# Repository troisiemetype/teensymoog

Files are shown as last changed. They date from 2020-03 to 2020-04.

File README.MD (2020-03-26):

# TeensyMoog

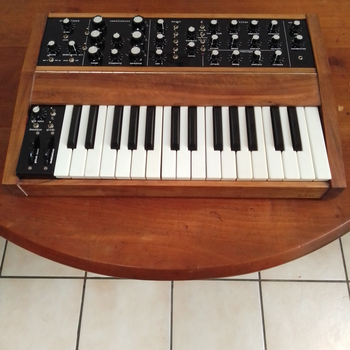
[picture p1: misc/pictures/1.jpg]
teensymoog 1

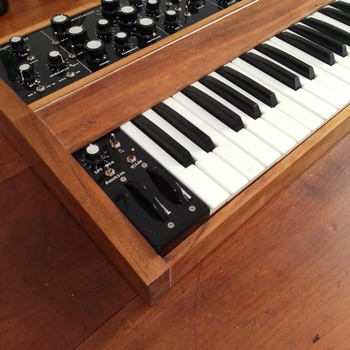
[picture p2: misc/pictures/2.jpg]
teensymoog 2

## What is it ?
_Teensymoog_ is a synth, inspired by the legendary minimoog.

It aims at looking and functioning as close as possible of the orinal, but using digital tools, namely Teensy and Arduino boards.

It uses three boards, one Teensy 4.0 that handles the heavy computing (sound generation), and two Arduino Mega (chinese copies in a small form factor), that are used as "port expander", which read keys, switches and potentiometers and send their value on change to the Teensy.

## How it's made :
It's based on a Teensy 4.0 running the incredible audio library by _Paul Stoffregen_ of [PJRC.com](https://www.pjrc.com/teensy/td_libs_Audio.html).

The whole interface (`minimoog_teensy/audio_setup.h`) has been developped with the associate [visual online audio system design tool](https://www.pjrc.com/teensy/gui)

Two Arduino Mega pro are used to poll all the switches and potentiometer and sending any update to the teesny. The communication between the boards uses MIDI messages, mainly control change (or continuous control) messages. I've tried to stick as close as possible to the MIDI specification, and using the existing and available control numbers. There are cases where it's not the case (_e.g._ filter cutoff frequency uses a two bytes control change to increase resolution).

A Pimoroni's phatDAC is used to output high quality audio from the i2s stream generated by the audio library. A USB B port is mounted on the rear panel so the synth can be connected to anything, as a USB midi device or USB audio device (not available in Arduino IDE for Teensy 4.0 yet, but I know it will come !). There is also provision for (not implemented yet !) MIDI in and out (DIN-5 pins, but maybe 3.5 jack would be a better idea) sustain and expression.

A smartphone charger has been repurpose as the main adaptor.

The enclosure has been made out of would and acrylic.

The base plate is made of plywood. The mains parts are made of walnut, from a table I found in the street two years ago. For a long time I wanted to repair it, but I didn't like its feet, so this is a good opportunity to make room in there ! The wood has been treated with tung oil, wich gives a soft and smooth finish that I really love.

The main and lateral control panels, control panel bottom and rear enclosure are made of 2mm acrylic (PMMA). It has been cut and engrave with a CO2 laser cutter. The engravures are filled with white paint. SVG files for the panels are included in the repository.

There was no sketch made for the walnut enclosure, but I should have done some : it's quite thin (around 7cm tall), and it gave me headaches to integrate some components in it. There is plenty of room, but I had to change things several time to accomodate the keyboard height, the front panel with sontrols and the rear panel with plugs...

#### Dependencies
Apart from Teensy audio, this program uses a few libraries.
[Arduino Midi library by FortySevenEffects](https://github.com/FortySevenEffects/arduino_midi_library), for internal communication between the boards. It's the one implemented by Teensy for usb MIDI, very complete.

[PushButton](https://github.com/troisiemetype/PushButton) is used to debounce all switches, and detect changes.

[expFilter](https://github.com/troisiemetype/expfilter) is used to smooth ADC readings. It gives a result close to a running average, but without the need of big tables to store results.

## Function implemented
As said above, the goal is to have something looking as close as possible to the original Minimoog.

The keyboard is smaller, 2 1/2 cotaves instead of 3 1/2 (or 30 keys instead of 44), not by choice, but because the _Bontempi_ electric organ it cames from.

### Global description
It has three oscillators, a mixer section with noise and feedback (post-filter output is re-fed to the mixer), a filter, two envelopes generator for filter and notes, a LFO, a pitchbend wheel and a modulation wheel.

### Oscillators
Oscillators have each six waveforms to choose from, six frequency range (or octave transposition) and osc. 2 & 3 can be detuned by +- 1 octave regarding the base note. Osc.3 can be disconnected from the keyboard control, and used as a drone.

### Noise
There is one noise source, with pink and white noise.

### Feedback
The original minimoog has a external input mixer entry, so anything (guitar, another synth, etc) could be processed through the mixer. It was often used as a feedback path by plugin the headphone jack back into this input. The minimoog reissue has hard-wired this by connecting the output to this external input internally when nothing is connected to the jack.

Maybe external input will be implemented once, but I wanted this feedback.

### Mixer
The mixer is copy-paste on the original minimoog : a potentiometer for each of the five channels, and a switch for rapid on / off.

### Filter
The filter is (I believe) close from the minimoog one. Cutoff frequency and emphasis (resonance) are available. Their is an associated envelope generator that modulates the cutoff frequency. Their is also an addition compared to the minimoog : there is a knob to slide continuously from low pass to band pass, to high pass filter. It can also slide continuously from low pass to high pass, thus resulting in a band stop filter at mid-course. (see _functions_ above)

### Envelope generator
There are two envelope generators : one for the filter, the other for the global sound shape. On the original minimoog, decay can be used (_via_ a switch) to add release to notes. On this one a knob is there for, so this is a classic ADSR envelope.

### LFO
There is a LFO available, with continuous rate and waveform selection.

### Modulation
The modulation can be applied to oscillators and or filter, and is controlled by the modulation wheel. Four modulation sources can be used, and mix together. osc.3 or filter envelope can be mixed to noise or LFO.

### Glide (portamento)
Portamento can be from 0 to ten seconds, and switch on and off.

### Octave transpose
There is +- 2 octave transpose available to compensate the only 2 1/2 octave from the keyboard.

### Function settings
There are "hidden" settings available through a function switch. When turn on, the keyboard can be used to change the behavior of some things. Each of this setting is saved when power is turned off.
The first octave of the keyboard is used to select the setting to be changed, then keys from the second C used to set the new value.

#### Keyboard priority mode
_Function + C_

This defines the way the keyboard behave. There are four mode available :
1. lower note priority : a note will be played only if it's lower than the one already playing.
1. first note priority : a note will be played only if no note is already playing.
1. last note priority : a note will be played anyway.
1. upper note priority : a note will be played only if it's upper than the one already playing.
In any case, ten notes are tracked, so when several key are pressed releasing a key will play another, according to their position or the order they was pressed.

#### Note retrigger
_Function + D_

This defines how a new note is played. If some keys are already pressed when a new note is played, it can retrigger the envelopes, or let them to their state. This can be turned on or off.

#### Keyboard detune
_Function + E_

The original minimoog has a resistor ladder keyboard, which implies small variations in tonality regarding a perfect pitch. This setting reproduce this by applying detune to each note and letting you choice : 
1. off : perfect pitch for each key
1. soft : lightly detuned, +-10% of a semitone
1. medium : a bit more detuned, +-30%
1. hard : play drunk, two adjacent notes can almost same the same, +-50%
1. reset : this generate a new random detune table.
The detune table stores a fix detune coefficient for each of all 128 MIDI notes.

#### Bitcrush
_Function + F_

Output resolution can be changed. The default is 16 bits, but any bitsize between 4 and 16 can be choose.
The bitcrushing is applied at the end of the audio stream, just before the i2s / USB output.

#### Filter mode
_Function + G_

The filter band knob slides continuously from low pass to high pass. It can be choosen wether :
* it slides from low pass to band pass for the lower half (high pass cut), and from band pass to high pass in the upper half (low pass cut), or
* it slides continuously from low pass to high pass, thus resulting in a band stop filter when knob is centered. (well, kind of : having a true band stop filter would mean to mix two different filters with frequency offsets. Here they overlap.)

#### MIDI channel setting
_Function + A_ for MIDI in

_Function + B_ for MIDI out

The MIDI channel the synth listens and emit on when connected _via_ USB can be changed. Any channel from 1 to 16.

#### Pitchbend range
_Function + pitchbend wheel move_

The amount the pitch wheel bends a note above or bellow the note being played can be changed semitone by semitone.

#### Modulation range
_Function + modulation wheel move_

As well as the pitch bend range can be changed, so does the modulation range. Pressing any key will set this interval according to second C, for the modulation applied to oscillators. Modulation applied to filter can be changed as well, by pressing second C before to set the new interval.

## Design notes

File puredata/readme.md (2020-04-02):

### Pure Data patches
These patch has been used when writing the main code running on Teensy, to setup the audio layout and test things.
The panel sends the CC on midi channel 1.
The (very basic !) keyboard sends note on and note off on channel 1 too.

You can use it by uncommenting the 4 usbMIDI commented lines in setup, that maps the  usbMIDI to internal midi functions. The majority of the audio functions of the synth can be accessed, without having a physical interface, like keyboard, knobs, switches, etc. The only thing you need here is the Teensy and an audio DAC.

It has been used before the CC LSB were implemented, so maybe

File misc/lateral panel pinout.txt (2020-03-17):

0		GND
1		5V
2		pitch bend
3		mod wheel
4		LFO rate
5		glide
6		LFO shape
7		function
8		not used

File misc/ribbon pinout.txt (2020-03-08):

0		5V
1		GND
2		modulation mix
3		glide
4		osc1 range
5		osc2 range
6		osc3 range
7		osc1 waveform
8		osc2 waveform
9		osc3 waveform
10		osc1 mix
11		osc2 mix
12		osc3 mix
13		noise mix
14		feedback mix
15		modulation mix 1
16		modulation mix 2
17		osc modulation
18		osc3 ctrl
19		transpose +
20		transpose -
21		osc1 mix sw
22		osc2 mix sw
23		osc3 mix sw
24		noise mix sw
25		feedback mix sw
26		noise color
27		mega 2 rx from teensy
28		mega 2 tx to teensy
29		mega 2 reset
30		
31		
32		
33

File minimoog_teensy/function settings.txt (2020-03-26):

Keyboard mode
				note : in any case, when there are several notes pressed, releasing one will trigger another, according to priority mode.
	first		The first key pressed has priority. It must be released for another to trigger note
	last		Last key pressed triggers new note.
	lower		The lower key on the keyboard has priority
	upper		The upper key has priority

Bitcrush
				bit crusher : reduce resolution of the samples before output
	4 - 16

Midi in channel
				the channel the synth reacts to when connected to USB MIDI
	1 - 16

Midi out channel
				the channel the synths sends on
	1 - 16

Retrigger
				when a key is pressed and there was already one (or several), retrigger the envelope or no
	0 / 1

Detune
				Add a small amount of detune to each note, to simulate a resistor ladder vintage keyboard
	off
	soft
	medium
	hard
	reset

filter mode
				The filter band can be changed steplessly from low pass to high pass.
				This gives the choice of how it behave at mid course
	Band pass	The lower half of the control mixes low pass with band pass. High pass cut.
				The upper half mixes band pass with high pass. Low pass cut.
	Band stop	The low and high pass are mixed continuously, band pass cut, resulting in a band stop
				on middle position.

pitchbend range
				Any interval regarding the note beeing played can be choosen for the pitchbend.

modulation range
				The modulation range can be changed independently for the oscillators and for the filter.

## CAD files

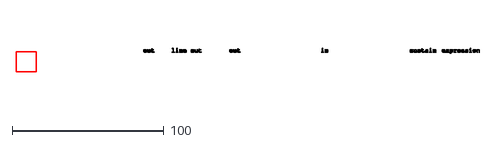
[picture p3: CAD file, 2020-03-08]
panels/dxf/minimoog - capot arrière inferieur - texte.dxf
306.0 x 15.5

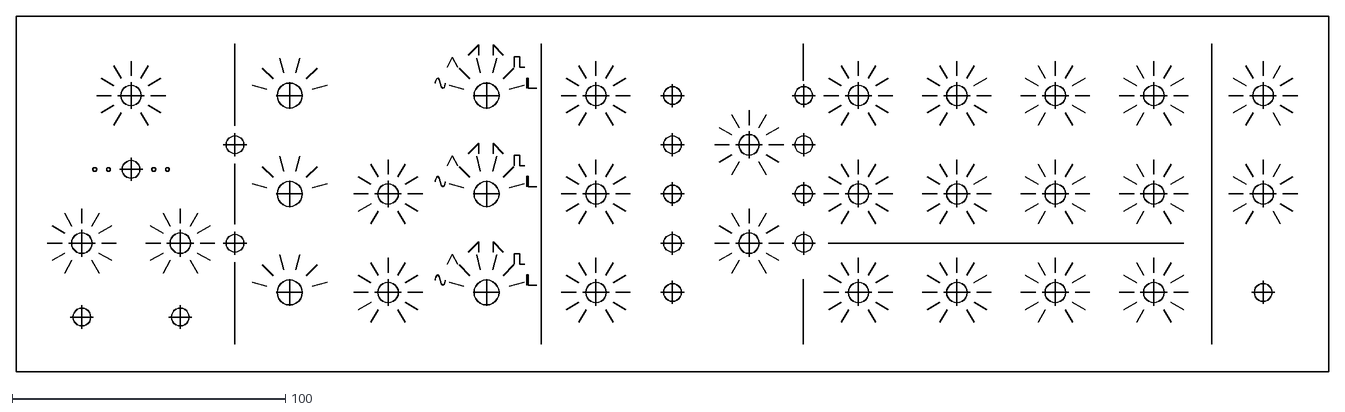
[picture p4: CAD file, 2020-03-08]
panels/dxf/minimoog - facade.dxf
480.0 x 130.0

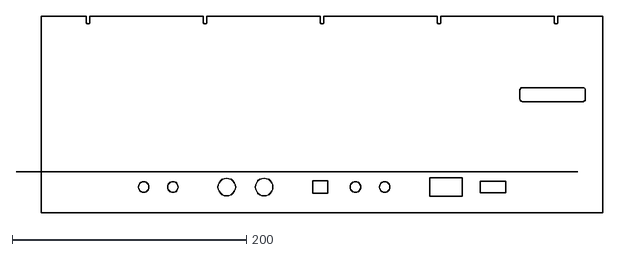
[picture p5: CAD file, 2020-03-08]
panels/dxf/minimoog - capot arrière inferieur.dxf
501.5 x 168.0

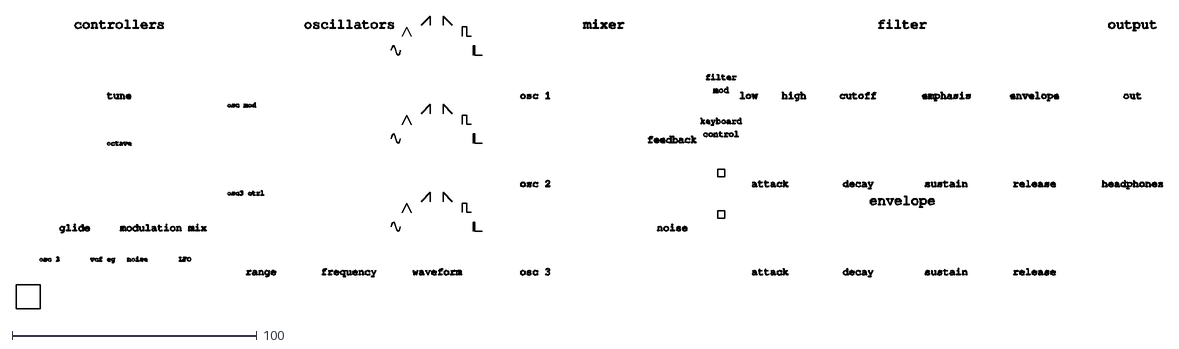
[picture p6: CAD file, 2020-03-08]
panels/dxf/minimoog - facade 3 - texte applati.dxf
468.4 x 119.5

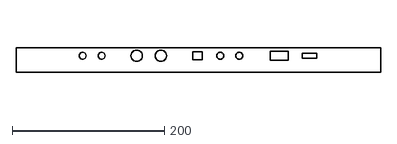
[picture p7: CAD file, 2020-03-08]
panels/dxf/minimoog - capot arrière inferieur - doublure.dxf
479.7 x 32.7

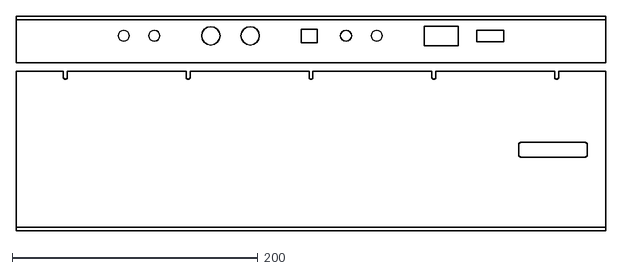
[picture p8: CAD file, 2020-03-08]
panels/dxf/minimoog - capot fond inferieur.dxf
480.0 x 174.7

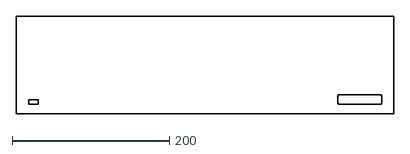
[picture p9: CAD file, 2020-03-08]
panels/dxf/minimoog - capot arrière supérieur.dxf
480.0 x 123.8

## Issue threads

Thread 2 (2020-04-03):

Good job!

benwadub, 2020-04-03:
Hello, i just start my investigation to make my first teensy synth and I called on your project it seems very good!
Is it possible to use only the teensy .ino to play the synth with a teensy controller already built or an existing midi keyboard?
I m looking for a project to start with cause I m really new to programming so I need to learn and didn’t find how to use the audio library with my midi keyboard :-(
Sorry for my poor English I m French!

troisiemetype, 2020-04-03:
Hi Ben.

Pas de problème pour l'anglais, je ne relève pas, je suis français aussi ! ;)
(but I'll go on in english, sorry...)

You can use only the Teensy part, yes. You'll have some minor modifications to do, as :
* implement the MIDI-in part if you want to use MIDI DIN connectors. It should be straightforward, you just have to create a hardware Serial (there are 7 on the Teensy 4.0, choose whichever you need). If you want to make the synth without the keyboard part, you just have to map note on and note off, pitchbend, and mod wheel. For modwheel you may need to create a handler new handler for CC and implement only modwheel in it, so the external midi don't mess with other CC that are used internally. If you want to control others things, you should as well implement them. Some controls I used have a different CC number, but 7 bits was not enough to me for some controls.
* Remember MIDI plugs have to be isolated with an optocoupler. You find schematics on the web. And maybe modules too.
* Teensy has not enough IO for every switches and potentiometers, that's why I used two others Mega boards. But the Audio part uses around 5% of the CPU time, so you can use a port expander or multiplexer to connect everything and handle it with Teensy. There's plenty of room for it.

Hope that answers to your questions !

benwadub, 2020-04-04:
No problem to continue in English, It s better for everyone that ´ll read this later! I ll check the teensy code, no problem for me to make a midi in/out/thru I already built one for my controler!
I ll try to make an expander version of your synth to sequence it with my elektron digitakt!
Merci du Jura

benwadub, 2020-04-04:
hi just a question, if my midi notes come from a sequencer via midi din does the teensy recognize all note on and note off? If not I don t know how to setup each midi note if they don t come from a pin or mux

troisiemetype, 2020-04-04:
Hi,

If you look at the code, you will see that are too handlers for note on and note off.
* One is the __internal__ handler. It takes every notes coming for the first Arduino mega, offset them (the mega sends pitch from 0 to 30), echo them to MIDI out, then sends them to :
* __global__ handler, which is also the __external__ handler. This one handles note priority priority mode, and calls _note on_ and _note off_ functions when needed.

It's the same for note off messages.

On the two tracks I've recorded with the synth, I've recorded the midi parts with Ardour, then quantize them and played back trough the synth to record audio. ;)

benwadub, 2020-04-04:
ok so if I understand well it should work out of the box!
I just have to compile your code and mine and I could control your synth with my controller!
does my code interest you? it s a midi mixer with 8 midi channels 40 pots 8 faders and 8 encoders, 8 midi notes and 8 buttons for mute using the great tttapa control surface library
I can give it to you if you want!

troisiemetype, 2020-04-04:
Yeah, it could be usefull ! I was thinking about making a midi mixer for easier use of Ardour ! Don't you have a repository for it ?

benwadub, 2020-04-04:
i don t have a repository, I m a very noob at all this! I m a food truck owner so with this corona crisis I get time to learn things here is my code
```cpp

#include <Encoder.h>

// celà doit etre écrit avant la library control surface
#include <Control_Surface.h> // Inclu la library control surface téléchargeable ici https://github.com/tttapa/Control-Surface en cliquant le bouton vert a droite
 //USBDebugMIDI_Interface midi = 115200; // enlever les // en début de ligne pour entrer en mode debug usb et voir dans le panneau de control si vos controler envoient bien les infos

//auto &serial = Serial1;// Selectionne le port série à utiliser remplacer par serial pour une arduino
USBMIDI_Interface usbmidi;// enlever les / en debut de ligne pour activer l'interface usb, penser à désactiver l'interface série(din)
//SerialMIDI_Interface<decltype(serial)> midi = {serial, MIDI_BAUD

//};// démarre une interface midi serial au midi baud rate par defaut

//  ces lignes midi servent à activer un bouton qui envoit une note midi enlever les // sur ces 5 lignes pour l'activer

// démarrer une touche midi

CD74HC4067 mux1 = {
  A2,       // numéro de broche de l'arduino
  {2, 3, 4, 5} // numéro de pins de l'arduino sur lesquels sont branchés tous les multiplexeurs apellés mux S0, S1, S2
};
Bank<2> bank2 = {8}; // active 2 bank avec 8 adresses par bank
//démarre un multiplexeur pour 8 boutons mute
Bankable::CCButtonLatched <8> buttonmute[] = { //ces lignes déclarent le mux
  {{bank2,BankType::CHANGE_CHANNEL}, mux1.pin(0), {94, CHANNEL_1}},//numéro de bank correspondant/indique que le changement de bank change le canal midi (+8 car on a 8 adresses par bank)/pin sur laquelle le controleur est branché/numéro de cc/numéro de canal midi
  {{bank2,BankType::CHANGE_CHANNEL},mux1.pin(1), {94, CHANNEL_2}},
  {{bank2,BankType::CHANGE_CHANNEL},mux1.pin(2), {94, CHANNEL_3}},
  {{bank2,BankType::CHANGE_CHANNEL},mux1.pin(3), {94, CHANNEL_4}},
  {{bank2,BankType::CHANGE_CHANNEL},mux1.pin(4), {94, CHANNEL_5}},
  {{bank2,BankType::CHANGE_CHANNEL},mux1.pin(5), {94, CHANNEL_6}},
  {{bank2,BankType::CHANGE_CHANNEL},mux1.pin(6), {94, CHANNEL_7}},
  {{bank2,BankType::CHANGE_CHANNEL},mux1.pin(7), {94, CHANNEL_8}},
};

Bank<2> bank1 = {-8}; // 2 banks, 8 addresse per banks

CD74HC4067 mux2 = {// deuxième multiplexeur cette fois si avec 16 entrées
  A0,              // analog pin
  {2, 3, 4, 5}, // numero de pin du mux S0, S1, S2, S3
  // 7, // Optionally, specify the enable pin
};
//Instantiate multiplexer for 16 switch
Bankable::CCPotentiometer fx [] = {
  {{bank1, BankType::CHANGE_ADDRESS},mux2.pin(0), {83, CHANNEL_1}},
  {{bank1, BankType::CHANGE_ADDRESS},mux2.pin(1), {83, CHANNEL_2}},
  {{bank1, BankType::CHANGE_ADDRESS},mux2.pin(2), {83, CHANNEL_3}},
  {{bank1, BankType::CHANGE_ADDRESS},mux2.pin(3), {83, CHANNEL_4}},
  {{bank1, BankType::CHANGE_ADDRESS},mux2.pin(4), {83, CHANNEL_5}},
  {{bank1, BankType::CHANGE_ADDRESS},mux2.pin(5), {83, CHANNEL_6}},
  {{bank1, BankType::CHANGE_ADDRESS},mux2.pin(6), {83, CHANNEL_7}},
  {{bank1, BankType::CHANGE_ADDRESS},mux2.pin(7), {83, CHANNEL_8}},
  {{bank1, BankType::CHANGE_ADDRESS},mux2.pin(8), {82, CHANNEL_1}},
  {{bank1, BankType::CHANGE_ADDRESS},mux2.pin(9), {82, CHANNEL_2}},
  {{bank1, BankType::CHANGE_ADDRESS},mux2.pin(10), {82, CHANNEL_3}},
  {{bank1, BankType::CHANGE_ADDRESS},mux2.pin(11), {82, CHANNEL_4}},
  {{bank1, BankType::CHANGE_ADDRESS},mux2.pin(12), {82, CHANNEL_5}},
  {{bank1, BankType::CHANGE_ADDRESS},mux2.pin(13), {82, CHANNEL_6}},
  {{bank1, BankType::CHANGE_ADDRESS},mux2.pin(14), {82, CHANNEL_7}},
  {{bank1, BankType::CHANGE_ADDRESS},mux2.pin(15), {82, CHANNEL_8}},
};

Bank <2> bank3 = {8}; // 2 banks, 8 addresse per banks

  //Instantiate second multiplexer for 8 potentiometer
CD74HC4067 mux3 = {
  A1
  ,       // Analog input pin
  {2, 3, 4, 5} // Address pins S0, S1, S2};

};
Bankable::CCPotentiometer fader [] = { //ici on déclare les faders avec comme vu plus haut le numéro de CC et le canal
  {{bank3, BankType::CHANGE_CHANNEL}, mux3.pin(0), {7, CHANNEL_1}},
  {{bank3, BankType::CHANGE_CHANNEL}, mux3.pin(1), {7, CHANNEL_2}},
  {{bank3, BankType::CHANGE_CHANNEL}, mux3.pin(2), {7, CHANNEL_3}},
  {{bank3, BankType::CHANGE_CHANNEL}, mux3.pin(3), {7, CHANNEL_4}},
  {{bank3, BankType::CHANGE_CHANNEL}, mux3.pin(4), {7, CHANNEL_5}},
  {{bank3, BankType::CHANGE_CHANNEL}, mux3.pin(5), {7, CHANNEL_6}},
  {{bank3, BankType::CHANGE_CHANNEL}, mux3.pin(6), {7, CHANNEL_7}},
  {{bank3, BankType::CHANGE_CHANNEL}, mux3.pin(7), {7, CHANNEL_8}},

};

CCAbsoluteEncoder encoder [16] = {
  {{6, 7}, {85, CHANNEL_16},8, 4,},// pins sur lesquels sont branchés les encodeurs/numero cc/canal midi/multiplicateur de vitesse/ nombre de cran par tic de l'encodeur
  {{8, 9}, {86, CHANNEL_16}, 16, 4,},
  {{10, 11}, {87, CHANNEL_16}, 16, 4,},
  {{12, 13}, {88, CHANNEL_16}, 16, 4,},
  {{17, 18}, {89, CHANNEL_16}, 16, 4,},
  {{19, 20}, {90, CHANNEL_16}, 16, 4,},
  {{21, 22}, {91, CHANNEL_16}, 16, 4,},
  {{24, 25}, {92, CHANNEL_16}, 16, 4,},
  /*
  {{26, 27}, {24, CHANNEL_16}, 16, 4,},
  {{28, 29}, {25, CHANNEL_16}, 16, 4,},
  {{30, 31}, {26, CHANNEL_16}, 16, 4,},
  {{32, 33}, {27, CHANNEL_16}, 16, 4,},
  {{34, 35}, {28, CHANNEL_16}, 16, 4,},
  {{36, 37}, {29, CHANNEL_16}, 16, 4,},
  {{38, 39}, {30, CHANNEL_16}, 16, 4,},
  {{A21, A22}, {31, CHANNEL_16}, 16, 4,},
*/
};

using namespace MIDI_Notes;

NoteButton pads[] = {
  {5, {note(C, 2), CHANNEL_1}},
  {6, {note(C, 2), CHANNEL_2}},
  {7, {note(C, 2), CHANNEL_3}},
  {8, {note(C, 2), CHANNEL_4}},
  {9, {note(C, 2), CHANNEL_5}},
  {10, {note(C, 2), CHANNEL_6}},
  {11, {note(C, 2), CHANNEL_7}},
  {12, {note(C, 2), CHANNEL_8}},// Note C4 on MIDI channel 1
};
void setup() {
  Control_Surface.begin(); // initialise la library surface de control

}                   
void loop() {

  Control_Surface.loop(); // Update the Control Surface

}```
feel free to use it mod it and share it
there is usb midi or serial you ll find easily how to switch!

benwadub, 2020-04-04:
I can t find how to send midi from usb with the teensy code and receive audio from usb too,
I changed the audio input in audio setup of the code
Ableton Live recognize the teensy as audio device
I included midiusb.h
but can't hear anything from the synth, could you explain all the midi interface in the sketch please?
I thought that the way I did I should send midi to teensy via usb and take the audio from teensy via usb
if you have can show me where I must investigate it would be nice!
(i don t have the teensy audio board for the moment it s why I d like to test via usb only for the moment!)

troisiemetype, 2020-04-04:
For MIDI in, you have nothing to do, it already works as is. At least for note triggering.
Every step in the audio chain is initialized, so you should hear something.
As you don't have external controls for now, you should comment out the two internal midi (that receive from Mega 1 and Mega 2) handler in setup.

You have to modify the audio_setup to replace I2S out by USB out. **And** you have to set the _USB type_ to MIDI + audio in the IDE before uploading your program to the board.

If you haven't seen it, there are explanations about how the audio library works, as well as a video tutorial that is worth the time.

Note : the stable version of Teensy loader doesn't include the option for USB audio on Teensy 4.0 yet, as it's under testing. But there is a beta version available (go and check the forum) which has it working.

benwadub, 2020-04-05:
i m on teensy3.5, I replaced audio output by usb and thought about the ice configuration too
i ll recheck the audio tutorial!

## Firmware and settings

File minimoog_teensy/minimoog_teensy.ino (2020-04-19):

// Minimoog - Teensy
/*
 * This program is part of a minimoog-like synthesizer based on teensy 4.0
 * Copyright (C) 2020  Pierre-Loup Martin
 *
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
 * You should have received a copy of the GNU General Public License
 * along with this program.  If not, see <http://www.gnu.org/licenses/>.
 */

/* This program is a synthesizer very similar to the minimoog model D.
 * It is intended to run on a Teensy 4.0, using the PJRC audio library.
 * It also uses two Arduino Mega boards to manage all the user inputs :
 * keyboard, switches, potentiometers, etc.
 * All user inputs are handled and send to the teensy board using midi commands
 */

 /*
  * Pinout
  *
  * RX from mega 1 (through tension divider) 		0
  * TX to mega 1 (serial 1)							1
  * mega 1 reset 									2
  * 	
  * RX from mega 2 (through tension divider) 		16
  * TX to mega 2 (serial 4)							17
  * mega 2 reset 									18
  * 	
  * I2S OUT1A 										7
  * I2S LRCLK1										20
  * I2S BCLK1 										21
  *
  * There are provision on the rear panel for sustain and expression control, not implemented yet.
  */

#include <Audio.h>
#include <Wire.h>
#include <SPI.h>
#include <SD.h>
#include <SerialFlash.h>
#include <EEPROM.h>

#include "audio_setup.h"
#include "defs.h"

#include "MIDI.h"					// https://github.com/troisiemetype/PushButton
// #include "Timer.h"

// constants

const int8_t MEMORY_ID = 0;

// my pots never go full clockwise... :/ So this can be used to adapt their range.
// These two commented out values for testing with external midi triggering (like puredata).
//const uint16_t RESO = 127;
//const uint16_t RESO = 16383;
const uint16_t RESO = 1005;
const uint16_t HALF_RESO = RESO / 2;

// There is a function that handles and tracks the key presses. Here is the max.
// It can me more, but whith ten fingers on a monophonic synth, I think this is enough !
const uint8_t KEYTRACK_MAX = 10;

// Mega1 sends midi note 0 for the lower note ; we offset it by for octave to get into the usefull range
const uint8_t MIDI_OFFSET = 48;
// To be modified according to keybed used. It's actualy not used, and any note can be handled from MIDI in.
const uint8_t NUM_KEYS = 30;

// Octave range for oscillators and filter.
const uint8_t MAX_OCTAVE = 10;
const uint8_t FILTER_MAX_OCTAVE = 5;

// The base for computing DC levels for keys, modulation, pitchbend, etc.
const float NOTE_MIDI_0 = 8.1757989156434;
const float NOTE_RATIO = 1.0594630943593;
const float HALFTONE_TO_DC = (float)1 / (MAX_OCTAVE * 12);
const float FILTER_HALFTONE_TO_DC = (float)1 / (FILTER_MAX_OCTAVE * 12);

// Filter base frequency : the filter cutoff frequency varies around this value.
const float FILTER_BASE_FREQUENCY = 440.0;
const float FILTER_BASE_NOTE = (log(FILTER_BASE_FREQUENCY / NOTE_MIDI_0)) / (log(NOTE_RATIO));
// This corresponds to the min and max values for the variable filter available in the Teensy Audio library,
// which is used by the synth.
/* Note about the state variable (Chamberlin) filter:
 * 	This filter can self oscillate, if given a resonnance value of around 50000.
 *	(and the library modified to accept such value ; the setter limits it to 5).
 *	It gives a nice sounding, pure sinewave.
 * 	Problem is, usefull range for varying resonnace is about what the bare library allows (from 0.7 to 5).
 *	It would be nice to test some exponential course to enable both continuous resonance modification AND self-oscillation.
 *	I've tried some modifications, but couldn't come to something usable.
 */
const float FILTER_MIN_Q = 0.7;
const float FILTER_MAX_Q = 5;
const float FILTER_DIV_Q = RESO / (FILTER_MAX_Q - FILTER_MIN_Q);

// Max mixer value for eahc channel if we want to avoid clipping.
// Value of 1 can be used, but induces distortion when more than one oscillator is used.
// Feedback should have its own value. If MAX_MIX is one feedback is powerfull,
// but with this value the difference with and without feedback is barrely noticeable.
const float MAX_MIX = 0.32;

// To be put in Mega1 sketch, so it sends a value on 14 bits.
// Note : the pitchbend wheel poses problems on the other sketch. For now it will stay like that,
// but there is room for improvement.
//343 - 492 - 500 - 651
const int16_t PITCH_BEND_MIN = 343;
const int16_t PITCH_BEND_MAX = 651;
const int16_t PITCH_BEND_NEUTRAL = PITCH_BEND_MIN + (PITCH_BEND_MAX - PITCH_BEND_MIN) / 2;
const int16_t PITCH_BEND_COURSE = PITCH_BEND_MAX - PITCH_BEND_MIN;
const float PITCH_BEND_INTERNAL_TO_MIDI = 8192.0 / PITCH_BEND_COURSE;

// Maximum attack, decay, release and glide time (in milliseconds)
// These use an exponential course to have both fine-tune of low values and a great range.
const float MAX_ATTACK_TIME = 10000;
const float MAX_DECAY_TIME = 10000;
const float MAX_RELEASE_TIME = 10000;
const float MAX_GLIDE_TIME = 10000;
/*
// Moved to Mega 1
const uint16_t MOD_WHEEL_MIN = 360;
const uint16_t MOD_WHEEL_MAX = 666;
const uint16_t MOD_WHEEL_NEUTRAL = MOD_WHEEL_MIN + (MOD_WHEEL_MAX - MOD_WHEEL_MIN) / 2;
const uint16_t MOD_WHEEL_COURSE = MOD_WHEEL_MAX - MOD_WHEEL_MIN;
*/

// Teensy can reset both Mega, if needed.
const uint8_t MEGA1_RST = 2;
const uint8_t MEGA2_RST = 18;

// Addresses for settings storing in memory. It uses Arduino's EEPROM functions but is saved to RAM on Teensy 4.0.
const uint16_t EE_MEMORY_INIT = 0;
const uint16_t EE_BITCRUSH_ADD = 3;
const uint16_t EE_KEYBOARD_MODE_ADD = 4;
const uint16_t EE_MIDI_IN_CH_ADD = 5;
const uint16_t EE_MIDI_OUT_CH_ADD = 6;
const uint16_t EE_TRIGGER_ADD = 7;
const uint16_t EE_DETUNE_ADD = 8;
const uint16_t EE_FILTER_MODE = 9;
const uint16_t EE_PITCH_BEND_RANGE = 10;
const uint16_t EE_MOD_WHEEL_OSC_RANGE = 11;
const uint16_t EE_MOD_WHEEL_FILTER_RANGE = 12;
const uint16_t EE_DETUNE_TABLE_ADD = 20;

// variables
// Note : 
uint8_t internalMidiChannel = 1;
uint8_t midiInChannel = 1;
uint8_t midiOutChannel = 1;

float glide = 0;
bool glideEn  = 0;

bool noteRetrigger = 1;

bool filterKeyTrack1 = 0;
bool filterKeyTrack2 = 0;

int8_t transpose = 0;
bool function = 0;

bool oscMod = 0;
bool decay = 0;

// note : not used. It was intended to copy decay to release as on the orignal minimoog,
// but a release pot is present here.
// Anyway, the code is there, commented out, and there is a CC for it.
float filterDecay = 0;
float egDecay = 0;

// Stores the current band value, for recall when the band mode is changed.
int16_t filterBandValue = 0;

uint8_t pitchBendRange = 3;
uint8_t modWheelOscRange = 3;
uint8_t modWheelFilterRange = 12;

// Waveforms
uint8_t waveforms[6] = {WAVEFORM_SINE, WAVEFORM_TRIANGLE, WAVEFORM_SAWTOOTH,
						WAVEFORM_SAWTOOTH_REVERSE, WAVEFORM_SQUARE, WAVEFORM_PULSE};
// detune table. For emulating resistor-ladder keybed and induce key detuning.
float detuneTable[128];
// keyTrack
/*
 * Note on keytrack : there are two "keytracks" on the synth.
 *	One is the filter keytrack, that reflects the note being played on the filter's cutoff frequency.
 *	The other (this one) is a system tracks key being pressed to send not according to note priority setting.
 * A better name for one or the other should be found...
 */
uint8_t keyTrackIndex = 0;
struct {
	uint8_t key;
	uint8_t velocity;
} keyTrack[KEYTRACK_MAX];

int8_t nowPlaying = -1;

// double CC track
uint8_t ccTempValue[32];

enum function_t{
	FUNCTION_KEYBOARD_MODE = 0,
	FUNCTION_RETRIGGER,
	FUNCTION_DETUNE,
	FUNCTION_BITCRUSH,
	FUNCTION_FILTER_MODE,
	FUNCTION_MIDI_IN_CHANNEL,
	FUNCTION_MIDI_OUT_CHANNEL,
	FUNCTION_PITCH_BEND_RANGE,
	FUNCTION_MOD_WHEEL_OSC_RANGE,
	FUNCTION_MOD_WHEEL_FILTER_RANGE,
};

function_t currentFunction = FUNCTION_KEYBOARD_MODE;

enum keyMode_t{
	KEY_LOWER = 0,
	KEY_FIRST,
	KEY_LAST,
	KEY_UPPER,
};

keyMode_t keyMode = KEY_LAST;

enum detune_t{
	DETUNE_OFF = 0,
	DETUNE_SOFT,
	DETUNE_MEDIUM,
	DETUNE_HARD,
	DETUNE_RESET,
};

detune_t detune = DETUNE_OFF;
float detuneCoeff[4] = {0, 0.1, 0.3, 0.5};

enum filterMode_t{
	FILTER_BAND_PASS = 0,
	FILTER_BAND_STOP,
};

filterMode_t filterMode = FILTER_BAND_PASS;

uint8_t bitCrushLevel = 16;

struct midiSettings : public midi::DefaultSettings{
//	static const bool UseRunningStatus = true;
	static const long BaudRate = 115200;
};

// USB midi for sending and receiving to and from other device or computer.
MIDI_CREATE_DEFAULT_INSTANCE();
// The ones we use on synth for internal communication between Mega and Teensy
MIDI_CREATE_CUSTOM_INSTANCE(HardwareSerial, Serial1, midi1, midiSettings);
MIDI_CREATE_CUSTOM_INSTANCE(HardwareSerial, Serial4, midi2, midiSettings);

// for debug purpose, to send to serial the CPU used by audio library.
// Timer timerCPU;
// Timer timerGraph;

void initMemory(){
	uint16_t eeMemInit = EE_MEMORY_INIT;

	// Set the first three slots as a "flag" that tells us that memory is viable.
	EEPROM.write(eeMemInit++, 't');
	EEPROM.write(eeMemInit++, 'm');
	EEPROM.write(eeMemInit, MEMORY_ID);
/*
	Serial.println("memory init : ");
	eeMemInit = EE_MEMORY_INIT;
	for(uint8_t i = 0; i < 3; ++i){
		Serial.println(EEPROM.read(eeMemInit++));
	}
*/

	EEPROM.write(EE_BITCRUSH_ADD, bitCrushLevel);
	EEPROM.write(EE_KEYBOARD_MODE_ADD, KEY_LAST);
	EEPROM.write(EE_MIDI_IN_CH_ADD, midiInChannel);
	EEPROM.write(EE_MIDI_OUT_CH_ADD, midiOutChannel);
	EEPROM.write(EE_TRIGGER_ADD, noteRetrigger);
	EEPROM.write(EE_DETUNE_ADD, DETUNE_OFF);
	EEPROM.write(EE_FILTER_MODE, filterBandValue);
	EEPROM.write(EE_PITCH_BEND_RANGE, pitchBendRange);
	EEPROM.write(EE_MOD_WHEEL_OSC_RANGE, modWheelOscRange);
	EEPROM.write(EE_MOD_WHEEL_FILTER_RANGE, modWheelFilterRange);

	resetDetuneTable();
}

// Load the default values from settings
// This starts by a check for proper memory initialisation.
void loadMemory(){
	int8_t mem[3];
	uint16_t eeMemInit = EE_MEMORY_INIT;

	// Check if the memory needs initialisation :
	// first three slots are the letter 't' and 'm' (for TeensyMoog),
	// plus an ID set at the top of this file, that should be changed whenever memory needs a reset.
	// (i.e. when its mapping has been changed, or a setting has been added or removed, etc.)
//	Serial.println("memory check : ");
	for(uint8_t i = 0; i < 3; ++i){
		EEPROM.get(eeMemInit++, mem[i]);
//		Serial.println(mem[i]);
	}

	if((mem[0] != 't') || (mem[1] != 'm') || (mem[2] != MEMORY_ID)) initMemory();

	// Getting the settings from "eeprom"
	EEPROM.get(EE_BITCRUSH_ADD, bitCrushLevel);
	EEPROM.get(EE_KEYBOARD_MODE_ADD, keyMode);
	EEPROM.get(EE_MIDI_IN_CH_ADD, midiInChannel);
	EEPROM.get(EE_MIDI_OUT_CH_ADD, midiOutChannel);
	EEPROM.get(EE_TRIGGER_ADD, noteRetrigger);
	EEPROM.get(EE_DETUNE_ADD, detune);
	EEPROM.get(EE_FILTER_MODE, filterMode);
	EEPROM.get(EE_PITCH_BEND_RANGE, pitchBendRange);
	EEPROM.get(EE_MOD_WHEEL_OSC_RANGE, modWheelOscRange);
	EEPROM.get(EE_MOD_WHEEL_FILTER_RANGE, modWheelFilterRange);

	uint16_t address = EE_DETUNE_TABLE_ADD;
	for(uint16_t i = 0; i < 128; ++i){
		EEPROM.get(address, detuneTable[i]);
		address += 4;
	}

}

void setup() {

//	while(!Serial);

	pinMode(13, OUTPUT);
	digitalWrite(13, 1);

	// Mega resets
	pinMode(MEGA1_RST, OUTPUT);
	pinMode(MEGA2_RST, OUTPUT);
	digitalWrite(MEGA1_RST, 1);
	digitalWrite(MEGA2_RST, 1);

	// midi settings, start and callback
	midi1.begin(1);
	midi1.turnThruOff();
	midi1.setHandleNoteOn(handleInternalNoteOn);
	midi1.setHandleNoteOff(handleInternalNoteOff);
	midi1.setHandlePitchBend(handleInternalPitchBend);
	midi1.setHandleControlChange(handleControlChange);

	midi2.begin(1);
	midi2.turnThruOff();
	midi2.setHandleControlChange(handleControlChange);
/*
	Serial.begin(115200);
	Serial.println("started...");
*/
	// recall the settings stored in permanent memory.
	loadMemory();

	// TODO : check how to receive and transmit on different channels.
	usbMIDI.setHandleNoteOn(handleNoteOn);
	usbMIDI.setHandleNoteOff(handleNoteOff);
	usbMIDI.setHandlePitchChange(handlePitchBend);
//	usbMIDI.setHandleNoteOn(handleInternalNoteOn);
//	usbMIDI.setHandleNoteOff(handleInternalNoteOff);
//	usbMIDI.setHandlePitchBend(handleInternalPitchBend);
//	usbMIDI.setHandleControlChange(handleControlChange);
	usbMIDI.begin();

	AudioMemory(200);

	// audio settings
	// dc
	dcKeyTrack.amplitude(0.0);
	dcPitchBend.amplitude(0.0);
	dcFilterEnvelope.amplitude(1.0);
	dcFilter.amplitude(0.0);
	dcFilterKeyTrack.amplitude(0.0);
	dcOsc3.amplitude(0.2);
	dcLfoFreq.amplitude(0.0);
	dcOscTune.amplitude(0.0);
	dcOsc2Tune.amplitude(0.0);
	dcOsc3Tune.amplitude(0.0);
	dcPulse.amplitude(-0.95);

	// amp
	ampPitchBend.gain(pitchBendRange * HALFTONE_TO_DC * 2);
	ampModWheelOsc.gain(0.0);
	ampModWheelFilter.gain(0.0);
	ampPreFilter.gain(1.0);
	ampModEg.gain(0.1);
	ampOsc3Mod.gain(1);
	masterVolume.gain(1.0);

	osc1Waveform.frequencyModulation(MAX_OCTAVE);
	osc2Waveform.frequencyModulation(MAX_OCTAVE);
	osc3Waveform.frequencyModulation(MAX_OCTAVE);
	osc1Waveform.begin(1, NOTE_MIDI_0, WAVEFORM_TRIANGLE);
	osc2Waveform.begin(1, NOTE_MIDI_0, WAVEFORM_SAWTOOTH);
	osc3Waveform.begin(1, NOTE_MIDI_0, WAVEFORM_SQUARE);

	// noise
	whiteNoise.amplitude(1);
	pinkNoise.amplitude(1);

	// LFO
	lfoWaveform.begin(1, 0.1, WAVEFORM_TRIANGLE);
	lfoWaveform.frequencyModulation(11);

	// mixers
	mainTuneMixer.gain(0, 1);
	mainTuneMixer.gain(1, 1);
	mainTuneMixer.gain(2, 1);
	mainTuneMixer.gain(3, 1);
	osc2TuneMixer.gain(0, 1);
	osc2TuneMixer.gain(1, 1);
	osc3TuneMixer.gain(0, 1);
	osc3TuneMixer.gain(1, 1);

	oscMixer.gain(0, 1);
	oscMixer.gain(1, 0);
	oscMixer.gain(2, 0);
	oscMixer.gain(3, 0);

	globalMixer.gain(0, 1);
	globalMixer.gain(1, 0);
	globalMixer.gain(2, 1);

	noiseMixer.gain(0, 1);
	noiseMixer.gain(1, 0);

	osc3ControlMixer.gain(0, 1);
	osc3ControlMixer.gain(1, 0);

	modMix1.gain(0, 0);
	modMix1.gain(1, 1);
	modMix2.gain(0, 1);
	modMix2.gain(1, 0);
	modMixer.gain(0, 1);
	modMixer.gain(1, 0);

	filterMixer.gain(0, 0);
	filterMixer.gain(1, 0);
	filterMixer.gain(2, 1);
	filterMixer.gain(3, 0);

	bandMixer.gain(0, 1);
	bandMixer.gain(1, 0);
	bandMixer.gain(2, 0);

	// filter
	vcf.frequency(FILTER_BASE_FREQUENCY);
	vcf.resonance(0.7);
	vcf.octaveControl(FILTER_MAX_OCTAVE);

	// envelopes
	mainEnvelope.delay(0);
	mainEnvelope.attack(10);
	mainEnvelope.hold(0);
	mainEnvelope.decay(25);
	mainEnvelope.sustain(0.9);
	mainEnvelope.release(100);

	filterEnvelope.delay(0);
	filterEnvelope.attack(200);
	filterEnvelope.hold(0);
	filterEnvelope.decay(100);
	filterEnvelope.sustain(0.8);
	filterEnvelope.release(50);

	bitCrushOutput.bits(16);
	bitCrushOutput.sampleRate(44100.0);

	delay(500);

	digitalWrite(13, 0);
	delay(200);

// Blink. For debug. And letting a bit more time to Mega 1 to start.
	for(uint8_t i = 0; i < 5; ++i){
		digitalWrite(13, 1);
		delay(100);
		digitalWrite(13, 0);
		delay(50);
	}

//	Serial.println("asking for all controls");
	midi1.sendControlChange(CC_ASK_FOR_DATA, 127, 1);
	midi2.sendControlChange(CC_ASK_FOR_DATA, 127, 1);


/*
	timerCPU.init();
	timerCPU.setDelay(500);
	timerCPU.start(Timer::LOOP);
	Serial.print("max CPU usage");
	Serial.println(AudioProcessorUsageMax());
*/
/*
	timerGraph.init();
	timerGraph.setDelay(2);
	timerGraph.start(Timer::LOOP);
	printPostFilter.length(1);
*/
}

void loop() {
	midi1.read();
	midi2.read();
	usbMIDI.read(midiInChannel);
/*
	if(timerCPU.update()){
		Serial.print("cpu usage :");
		Serial.println(AudioProcessorUsage());
	}
*/
/*
	if(peakPreFilter.available()){
		Serial.print("pre filter  :\t");
		Serial.println(peakPreFilter.read());
	}
*/
/*
	if(peakPostFilter.available()){
		Serial.print("post filter :\t");
		Serial.println(peakPostFilter.read());
	}
*/

//	if(timerGraph.update()) printPostFilter.trigger();
}

// handle note on. compute dc to waveforms, glide enveloppe triggering, etc.
void noteOn(uint8_t note, uint8_t velocity, bool trigger = 1){
/*
	Serial.print("playing :");
	Serial.println(note);
*/
	// Note tracking.
	nowPlaying = note;
	// Applying detune per key.
	float fineTune = detuneTable[note] * detuneCoeff[detune];
//	float duration = 1.0 + (float)glideEn * (float)glide * 3.75;
	float duration = 1.0 + (float)glideEn * glide * MAX_GLIDE_TIME;
	float level = ((float)note + 12 * transpose) * HALFTONE_TO_DC;
	level += fineTune;
	// filter level is for cutoff freqeuncy keytrack. It's computed anyway, but enable through the corresponding mixer.
	float filterLevel = (((float)note - FILTER_BASE_NOTE) + (12 * transpose)) * FILTER_HALFTONE_TO_DC;
	filterLevel += fineTune;

	AudioNoInterrupts();
	dcKeyTrack.amplitude(level, duration);
	dcFilterKeyTrack.amplitude(filterLevel, duration);
	if(trigger){
		filterEnvelope.noteOn();
		mainEnvelope.noteOn();
	}
	AudioInterrupts();
}

// Stop note.
void noteOff(){
	AudioNoInterrupts();
	filterEnvelope.noteOff();
	mainEnvelope.noteOff();
	AudioInterrupts();
}

// Keytrack functions
// This one check if the key is the lower one, or not, and returns the index of the lower one.
int8_t keyTrackGetLower(uint8_t note){
	uint8_t lower = 127;
	int8_t lowerIndex = keyTrackIndex - 1;

	for(uint8_t i = 0; i < keyTrackIndex; ++i){
		if(keyTrack[i].key < lower){
			lower = keyTrack[i].key;
			lowerIndex = i;
		}
	}
/*
	Serial.print("lower note   : ");
	Serial.print(lower);
	Serial.print("\t index : ");
	Serial.println(lowerIndex);
*/
	return lowerIndex;
}

// Ditto upper key.
int8_t keyTrackGetUpper(uint8_t note){
	uint8_t upper = 0;
	int8_t upperIndex = keyTrackIndex - 1;

	for(uint8_t i = 0; i < keyTrackIndex; ++i){
		if(keyTrack[i].key > upper){
			upper = keyTrack[i].key;
			upperIndex = i;
		}
	}
/*
	Serial.print("upper note   : ");
	Serial.print(upper);
	Serial.print("\t index : ");
	Serial.println(upperIndex);
*/
	return upperIndex;
}

// Add a key to the keytrack table.
int8_t keyTrackAdd(uint8_t note, uint8_t velocity){
	// We only keep count of a limited quantity of notes !
	if (keyTrackIndex >= KEYTRACK_MAX) return -1;
/*
	Serial.print("note added   : ");
	Serial.print(note);
	Serial.print("\t index : ");
	Serial.println(keyTrackIndex);
*/
	keyTrack[keyTrackIndex].key = note;
	keyTrack[keyTrackIndex].velocity = velocity;

	return keyTrackIndex++;
}

// remove a key that has been released on the keyboard, and reorder all that were pressed after.
int8_t keyTrackRemove(uint8_t note){
	int8_t update = -1;
	for(uint8_t i = 0; i < keyTrackIndex; ++i){
		if(keyTrack[i].key == note){
			update = i;
			keyTrackIndex--;
			break;
		}
	}

	if(update >= 0){
/*
		Serial.print("note removed : ");
		Serial.print(note);
		Serial.print("\t index : ");
		Serial.println(update);
*/
		for(uint8_t i = update; i < keyTrackIndex; ++i){
			keyTrack[i] = keyTrack[i + 1];
		}
	}

	return update;
}

// Handle note on. Internal MIDI from Mega 1 lands here.
// Dispatch to settings if the function switch is enable.
// Apply the keyboard offset (Mega 1 has its first key corresponding to MIDI note 0)
// Echo the offset note to usbMIDI out.
void handleInternalNoteOn(uint8_t channel, uint8_t note, uint8_t velocity){
	if(function){
		handleKeyboardFunction(note, 1);
		return;
	}
	usbMIDI.sendNoteOn(note + MIDI_OFFSET + 12 * transpose, velocity, midiOutChannel);
	handleNoteOn(channel, note + MIDI_OFFSET, velocity);
}

// Handle note ON. usbMIDI in lands here.
// Define if the new note has to be played, according to notes already played and key priority.
void handleNoteOn(uint8_t channel, uint8_t note, uint8_t velocity){
/*
	Serial.print("note ");
	Serial.print(note);
	Serial.println(" on");
*/

	int8_t newIndex = -1;
	int8_t lowerIndex = -1;
	int8_t upperIndex = -1;
	switch(keyMode){
		// When KEY_FIRST, we play the note only if there is not one already playing
		// But we keep track of all notes depressed !
		case KEY_FIRST:
			if(keyTrackAdd(note, velocity) == 0)
			noteOn(note, velocity);
			break;
		// When KEY_LAST, we play the new note anyway.
		// And keep track. Of course.
		case KEY_LAST:
//			if(keyTrackAdd(note, velocity) >= 0) noteOn(note, velocity);
			newIndex = keyTrackAdd(note, velocity);
			if(newIndex == 0){
				noteOn(note, velocity, 1);
			} else if(newIndex > 0){
				noteOn(note, velocity, noteRetrigger);
			}
			break;
		case KEY_LOWER:
			// add note to the keytrack table.
			// check if there is a lower one.
			// if no, play the note.
			// if yes, do nothing.
//			Serial.println("handle note on");

			newIndex = keyTrackAdd(note, velocity);
			lowerIndex = keyTrackGetLower(note);
/*
			Serial.print("new   : ");
			Serial.print(newIndex);
			Serial.print("\tlower : ");
			Serial.println(lowerIndex);
*/
			if(lowerIndex == (keyTrackIndex - 1)){
				if(newIndex == 0){
					noteOn(note, velocity);
				} else if(newIndex > 0){
					noteOn(note, velocity, noteRetrigger);
				}
			}
			break;
		case KEY_UPPER:
			// add note to the keytrack table.
			// check if there is an upper one.
			// If no, play the note.
			// If yes, do nothing.
			newIndex = keyTrackAdd(note, velocity);
			upperIndex = keyTrackGetUpper(note);

			if(upperIndex == (keyTrackIndex - 1)){
				if(newIndex == 0){
					noteOn(note, velocity);
				} else if(newIndex > 0){
					noteOn(note, velocity, noteRetrigger);
				}
			}
			break;
		default:
			break;
	}

}

// handle internal note off.
// Apply offset from keyboard, echo to usb MIDI out.
void handleInternalNoteOff(uint8_t channel, uint8_t note, uint8_t velocity){
	if(function){
//		handleKeyboardFunction(note, 0);
		return;
	}
	usbMIDI.sendNoteOff(note + MIDI_OFFSET + 12 * transpose, 0, midiOutChannel);
	handleNoteOff(channel, note + MIDI_OFFSET, velocity);
}
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

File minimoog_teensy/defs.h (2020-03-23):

// Minimoog
/*
 * This program is part of a minimoog-like synthesizer based on teensy 4.0
 * Copyright (C) 2020  Pierre-Loup Martin
 *
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
 * You should have received a copy of the GNU General Public License
 * along with this program.  If not, see <http://www.gnu.org/licenses/>.
 */

/* This program is a synthesizer very similar to the minimoog model D.
 * It is intended to run on a Teensy 4.0, using the PJRC audio library.
 * It also uses two Arduino Mega boards to manage all the user inputs :
 * keyboard, switches, potentiometers, etc.
 * All user inputs are handled and send to the teensy board using midi commands
 */

#define CC0								0
#define CC1								1
#define CC2								2
#define CC3								3
#define CC4								4
#define CC5								5
#define CC6								6
#define CC7								7
#define CC8								8
#define CC9								9
#define CC10							10
#define CC11							11
#define CC12							12
#define CC13							13
#define CC14							14
#define CC15							15
#define CC16							16
#define CC17							17
#define CC18							18
#define CC19							19
#define CC20							20
#define CC21							21
#define CC22							22
#define CC23							23
#define CC24							24
#define CC25							25
#define CC26							26
#define CC27							27
#define CC28							28
#define CC29							29
#define CC30							30
#define CC31							31
#define CC32							32
#define CC33							33
#define CC34							34
#define CC35							35
#define CC36							36
#define CC37							37
#define CC38							38
#define CC39							39
#define CC40							40
#define CC41							41
#define CC42							42
#define CC43							43
#define CC44							44
#define CC45							45
#define CC46							46
#define CC47							47
#define CC48							48
#define CC49							49
#define CC50							50
#define CC51							51
#define CC52							52
#define CC53							53
#define CC54							54
#define CC55							55
#define CC56							56
#define CC57							57
#define CC58							58
#define CC59							59
#define CC60							60
#define CC61							61
#define CC62							62
#define CC63							63
#define CC64							64
#define CC65							65
#define CC66							66
#define CC67							67
#define CC68							68
#define CC69							69
#define CC70							70
#define CC71							71
#define CC72							72
#define CC73							73
#define CC74							74
#define CC75							75
#define CC76							76
#define CC77							77
#define CC78							78
#define CC79							79
#define CC80							80
#define CC81							81
#define CC82							82
#define CC83							83
#define CC84							84
#define CC85							85
#define CC86							86
#define CC87							87
#define CC88							88
#define CC89							89
#define CC90							90
#define CC91							91
#define CC92							92
#define CC93							93
#define CC94							94
#define CC95							95
#define CC96							96
#define CC97							97
#define CC98							98
#define CC99							99
#define CC100							100
#define CC101							101
#define CC102							102
#define CC103							103
#define CC104							104
#define CC105							105
#define CC106							106
#define CC107							107
#define CC108							108
#define CC109							109
#define CC110							110
#define CC111							111
#define CC112							112
#define CC113							113
#define CC114							114
#define CC115							115
#define CC116							116
#define CC117							117
#define CC118							118
#define CC119							119
#define CC120							120
#define CC121							121
#define CC122							122
#define CC123							123
#define CC124							124
#define CC125							125
#define CC126							126
#define CC127							127
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

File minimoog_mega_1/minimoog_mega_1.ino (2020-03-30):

// Minimoog - mega 1
/*
 * This program is part of a minimoog-like synthesizer based on teensy 4.0
 * Copyright (C) 2020  Pierre-Loup Martin
 *
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
 * You should have received a copy of the GNU General Public License
 * along with this program.  If not, see <http://www.gnu.org/licenses/>.
 */

/* This program is a synthesizer very similar to the minimoog model D.
 * It is intended to run on a Teensy 4.0, using the PJRC audio library.
 * It also uses two Arduino Mega boards to manage all the user inputs :
 * keyboard, switches, potentiometers, etc.
 * All user inputs are handled and send to the teensy board using midi commands
 */

/*
 * This program is for the Arduino Mega 1, it handles the readings of :
 * Category			input 				type		pin				MIDI
 * 
 * Keyboard
 *					Keys				switch 		22-51			note on / note off
 * Modulation
 *					LFO rate			pot			A0 				CC 30
 *					modulation mix 		pot			A1 				CC  3
 *					glide				pot			A2				CC  5
 *					pitchbend wheel		pot			A3				pitchbend change
 *					modulation wheel	pot			A4 				CC  1
 *					modulation mix 1	switch 		3				CC 117
 *					modulation mix 2 	switch 		2				CC 118
 *					osc modulation 		switch 		4 				CC 115
 *					glide				switch 		5				CC 65
 *					LFO waveform		switch 		6				CC 119
 * Oscillators
 *					osc 1 range			switch 		A5 				CC 102
 *					osc 1 waveform		switch 		A8 				CC 103
 *					osc 2 range			switch 		A6				CC 104
 *					osc 2 waveform		switch 		A9 				CC 105
 *					osc 3 range			switch 		A7 				CC 106
 *					osc 3 waveform		switch 		A10 			CC 107
 *					osc 3 control		switch 		7 				CC 108
 * Mixer
 *					osc 1 mix 			pot			A11				CC 85
 *					osc 2 mix 			pot			A12				CC 86
 *					osc 3 mix 			pot			A13				CC 87
 *					noise mix 			pot			A14				CC 88
 *					feedback mix 		pot			A15				CC 89
 *					osc 1				switch 		8 				Directly added to mix
 *					osc 2				switch 		9				ditto
 *					osc 3				switch 		10				ditto
 *					noise				switch 		11				ditto
 *					feedback			switch 		12				ditto
 *					noise color			switch 		17				CC 114 // led on 13 lowers tension
 * Other
 *					function			switch 		14 				CC 113
 *					transpose +			switch 		15 				CC 112
 *					transpose -			switch 		16				CC 112
 * Communication
 *					TX1 to teensy					18
 *					RX1 from teensy					19
 */

/*
 * Note on switches : every switch is active low, using the internal pull-up resistor.
 * The keys are active low with internal pull-up too.
 */
/*
 * Note on rotary selectors : the one I found are 12-positions selector, with a setting washer limiting their travel.
 * Here six positions are used, but more or less could be used as well to suit one needs for different waveforms.
 * They are wired with a resistor array between their pins, with ground on the first pin, +5V on the sixth pin,
 * and a 510ohm resistor between first and second pin, second and third, etc.
 * (five resistors total for a six-position switch)
 */
/*
 * Note on transpose (octave) switch : I used a three position temporary switch (ON)-OFF-(ON),
 * each of its (ON) pin mapped to a different digital input.
 * They share the same MIDI control command, sending 0 for octave - and 127 for octave +.
 * Two tact switches can be used instead of this three-position switch, without modification of the code.
 */

// includes
#include "MIDI.h"			// https://github.com/FortySevenEffects/arduino_midi_library
#include "PushButton.h"		// https://github.com/troisiemetype/PushButton
#include "ExpFilter.h"		// https://github.com/troisiemetype/expfilter
#include "defs.h"

// Constants
const uint8_t NUM_KEYS = 30;
// const uint8_t MIDI_OFFSET = 48; // moved to teensy !

const uint8_t NUM_SWITCHES = 15;
const uint8_t NUM_POTS = 16;
const uint8_t NUM_SELECTORS = 6;

const uint8_t POT_FILTER_COEF = 20;

// Digital pin definition
const uint8_t KEYS[NUM_KEYS] = {
	22, 23, 24, 25, 26, 27, 28, 29, 30, 31, 32, 33,
	34, 35, 36, 37, 38, 39, 40, 41, 42, 43, 44, 45,
	46, 47, 48, 49, 50, 51
};

PushButton keys[NUM_KEYS];

/*
 * For memory : pin definitions. Some have moved, I let them here in case it would be needed.
 * They could be used to init switch and pots tables and make them more readable,
 * but once they are set they are unlikely to be modified.
 */
/*
const uint8_t PIN_MOD_MIX_1 = 2;
const uint8_t PIN_MOD_MIX_2 = 3;
const uint8_t PIN_OSC_MOD = 4;
const uint8_t PIN_GLIDE = 5;
const uint8_t PIN_LFO_WAVEFORM = 6;
const uint8_t PIN_OSC3_CTRL = 7;

const uint8_t PIN_MIX_OSC_1 = 8;
const uint8_t PIN_MIX_OSC_2 = 9;
const uint8_t PIN_MIX_OSC_3 = 10;
const uint8_t PIN_MIX_OSC_NOISE = 11;
const uint8_t PIN_MIX_OSC_EXT = 12;
const uint8_t PIN_MIX_OSC_NOISE_COLOR = 13;
const uint8_t PIN_FUNCTION = 14;

const uint8_t PIN_TRANSPOSE_PLUS = 52;
const uint8_t PIN_TRANSPOSE_MINUS = 53;
*/
// Analog pin definition
/*
const uint8_t APIN_LFO_RATE = A0;
const uint8_t APIN_MOD_MIX = A1;
const uint8_t APIN_GLIDE = A2;
const uint8_t APIN_PITCH_WHEEL = A3;
const uint8_t APIN_MOD_WHEEL = A4;

const uint8_t APIN_OSC_1_RANGE = A5;
const uint8_t APIN_OSC_1_WAVEFORM = A6;
const uint8_t APIN_OSC_2_RANGE = A7;
const uint8_t APIN_OSC_2_WAVEFORM = A8;
const uint8_t APIN_OSC_3_RANGE = A9;
const uint8_t APIN_OSC_3_WAVEFORM = A10;

const uint8_t APIN_MIX_OSC_1 = A11;
const uint8_t APIN_MIX_OSC_2 = A12;
const uint8_t APIN_MIX_OSC_3 = A13;
const uint8_t APIN_MIX_NOISE = A14;
const uint8_t APIN_MIX_EXT = A15;
*/

// Every pin is defined through tables grouped by category. Pots, switches, keys (above).
// The main and setup loop can thus iterate the table to update every reanding easily.
const uint8_t APIN[NUM_POTS] = {A0, A1, A2, A3, A4, A5, A6, A7, A8, A9, A10, A11, A12, A13, A14, A15};

// Vars
// storing the last reading
uint16_t potState[NUM_POTS];

// switches pinout. Every switch is active low, and uses the internal pull-up resistor of the Atmega chip.
const uint8_t PIN[NUM_SWITCHES] = {3, 2, 4, 5, 6, 7, 8, 9, 10, 11, 12, 17, 14, 15, 16};

// Deboucing is handled by the push button library, as well as key initialisation and reading.
PushButton switches[NUM_SWITCHES];
// ExpFilter "debounces" ADC readings, filter noise. The readings only change when the users efectively moves a pot.
ExpFilter pots[NUM_POTS];
// 
uint8_t selectors[NUM_SELECTORS];

// Keyboard
bool keyState[NUM_KEYS];

// Mixer
// Mixer stores the values from potentiometers and switches, because switch turn channel on / off.
// Depending of the switch position, the value from the potentiometer is to be sent or not,
// and when turned on the potentiometer value has to be sent again.
uint16_t mix[5];
bool mixSw[5];

// Misc
uint8_t defaultVelocity = 64;

// update flag for data request from Teensy.
bool update = 0;

// Internal communication between the three boards ca be faster then MIDI standard. They handle it well.
// They could probably handle a baudrate of 250000 or 500000.
struct midiSettings : public midi::DefaultSettings{
//	static const bool UseRunningStatus = true;
	static const long BaudRate = 115200;
};
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

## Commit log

2020-03-08 Initial commit. Project almost running already.
    [Controls.ods, minimoog - capot arrière inferieur - doublure.dxf, minimoog - capot arrière inferieur - texte.dxf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]
2020-03-17 Hardware finished, softare running ok with some things to fix, like init values.
    [minimoog_mega_1.ino, minimoog_mega_2.ino, minimoog_teensy.ino]
2020-03-17 Modification made to filter, so keytrack works correctly by being adjusted to filter base frequency. Filter is self oscillating when used with feedback ! great
    [minimoog_mega_2.ino, minimoog_teensy.ino]
2020-03-18 Four modes of key track priority (first, last, lower, upper key) added.
2020-03-20 Tried to add pre-run for all the switches and pots of Mega 1, so main loop can run with properly initialized values. Failed to do so due to some obscure bug, maybe linked to arduino map() function, a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
    [defs.h, minimoog_mega_1.ino, minimoog_mega_2.ino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]
2020-03-22 Added main volume control. Added 1 ms offset to attack an release, to avoid clipping with 0 value. It seems that it's already implemented in the Audio Library, so it needs mors investigation. Added f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
    [defs.h, minimoog_mega_2.ino, minimoog_teensy.ino]
2020-03-23 Changed pot max resolution, because the pots I have never go up to 1024... Rewrite pitchbend functions, and implemented the same mecanism as for notes, to dissociate internal usb MIDI input. Added al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
2020-03-26 Modified mixer gain, and pre-filter gain, to avoid internal cliping.
    [minimoog_teensy.ino]
2020-03-26 Added a second modulation amplifier, so the oscillators and filter can have different levels. Tuned these amplifiers according to oscillators and filter range. Added function setting for modulation r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
    [minimoog_teensy.ino]
2020-03-30 Minor modifications. Modified (but commented out) audio setup for testing purpose. Completed comments to Mega 1 and Teensy sketches.

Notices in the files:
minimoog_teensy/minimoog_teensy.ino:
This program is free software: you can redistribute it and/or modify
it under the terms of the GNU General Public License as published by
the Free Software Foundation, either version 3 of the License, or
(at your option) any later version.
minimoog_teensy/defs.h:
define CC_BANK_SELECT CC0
